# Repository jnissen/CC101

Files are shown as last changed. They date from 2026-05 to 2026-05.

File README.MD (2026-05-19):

*Deutsch | [English](README.en.md)*

# Peerhof-Uni CC1101

KiCad-Projekt für eine kompakte Trägerplatine, die einen **ESP8266 (Wemos D1 Mini)** mit einem **CC1101 Sub-GHz-Funkmodul** (z. B. 433/868 MHz) kombiniert. Die Platine dient als universelles Funk-Gateway bzw. -Sender/Empfänger und lässt sich z. B. zur Anbindung von 433-MHz-Sensoren, Aktoren oder Smarthome-Komponenten an WLAN nutzen.

<p>
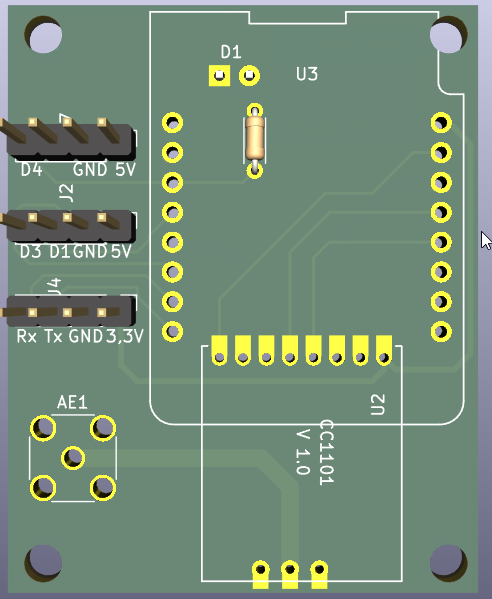
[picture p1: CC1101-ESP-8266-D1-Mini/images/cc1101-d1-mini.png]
CC1101 ESP8266 D1 Mini (Light)
  
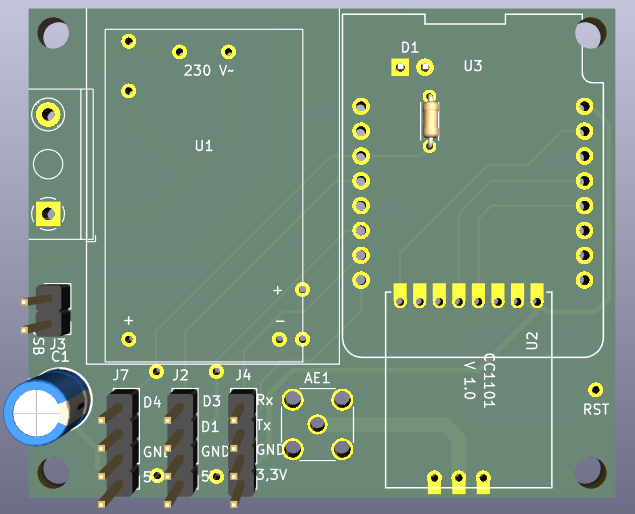
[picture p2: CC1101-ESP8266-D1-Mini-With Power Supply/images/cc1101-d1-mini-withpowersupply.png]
CC1101 ESP8266 D1 Mini mit Netzteil
  
</p>

## Projektvarianten

Das Repository enthält zwei Varianten desselben Designs:

- **[CC1101-ESP-8266-D1-Mini](CC1101-ESP-8266-D1-Mini/)** – *Light-Version*  
  Schlanke Variante ohne eigene Spannungsversorgung. Versorgung erfolgt direkt über den USB-Anschluss bzw. den 5-V-Pin des D1 Mini. Ideal, wenn bereits eine stabile 5-V-Quelle vorhanden ist.

- **[CC1101-ESP8266-D1-Mini-With Power Supply](CC1101-ESP8266-D1-Mini-With%20Power%20Supply/)** – *Variante mit Netzteil*  
  Erweiterte Version mit zusätzlicher Bordspannungsversorgung für den autarken Betrieb (z. B. direkt aus einer höheren DC-Eingangsspannung).

## Funktionen / Merkmale

- ESP8266 auf Basis des Wemos D1 Mini (WLAN, einfache Programmierung über USB).
- CC1101-Funkmodul für Sub-GHz-Kommunikation (ASK/OOK, FSK, GFSK, MSK).
- Herausgeführte Stiftleisten:
  - `J2`: D4 / GND / 5 V
  - `J3`: D3 / D1 / GND / 5 V
  - `J4`: RX / TX / GND / 3,3 V (UART)
- Pad-Feld `AE1` für eine externe Antenne / Helix-Antenne.
- Status-LED `D1`.
- Zweilagiges PCB-Design, fertige Gerber-Daten liegen jeweils im Ordner `gerber/`.

## Verzeichnisstruktur

```
CC1101-ESP-8266-D1-Mini/                  KiCad-Projekt (Light)
CC1101-ESP8266-D1-Mini-With Power Supply/ KiCad-Projekt (mit Netzteil)
└── gerber/                               Fertigungsdaten (Gerber + Bohrdatei)
```

## Verwendung

1. Projekt in **KiCad** öffnen (`.kicad_pro`).
2. Schaltplan (`.kicad_sch`) und Layout (`.kicad_pcb`) prüfen bzw. anpassen.
3. Gerber-Daten aus dem jeweiligen `gerber/`-Ordner an einen PCB-Hersteller übermitteln.
4. Bestücken, ESP8266 mit gewünschter Firmware flashen (z. B. ESPHome, Tasmota mit CC1101-Patch, eigene Arduino-Skizze) und an SPI-Pins des D1 Mini anschließen.

## Bezugsquellen

- CC1101-Funkmodul (Amazon, Affiliate-Link): <https://amzn.to/4uQriL0>
- Wemos D1 Mini (ESP8266) (Amazon, Affiliate-Link): <https://amzn.to/4tIXEXa>

## Lizenz

Dieses Projekt steht unter der **CERN-OHL-W-2.0** Lizenz: <https://ohwr.org/cern_ohl_w_v2.txt>

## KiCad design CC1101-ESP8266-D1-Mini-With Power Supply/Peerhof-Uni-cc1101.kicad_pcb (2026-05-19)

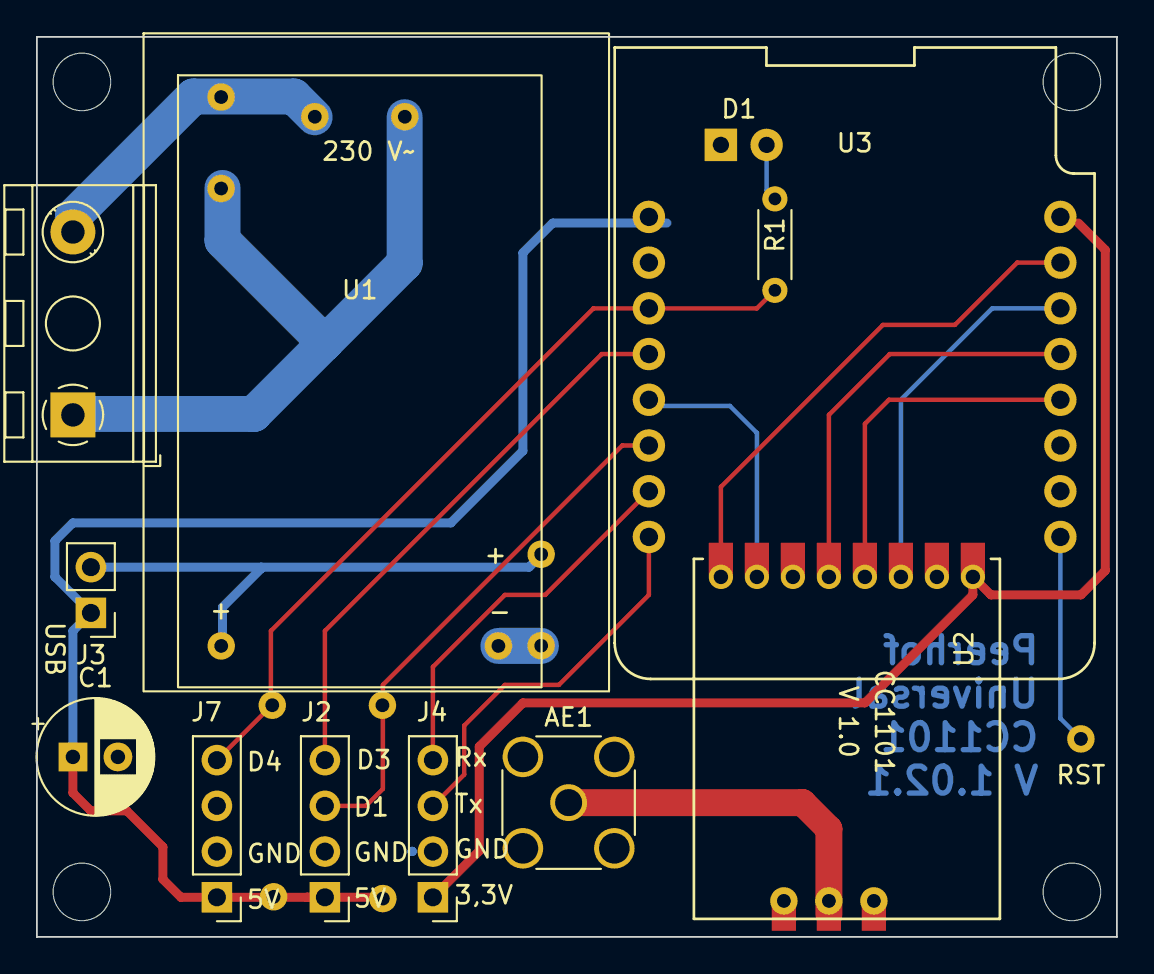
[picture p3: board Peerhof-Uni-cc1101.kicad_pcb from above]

Board: 2 copper layers, 60.0 x 50.0 mm, 12 parts (1 on the bottom side), 18 nets.

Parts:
AE1: Antenna_Shield; SMA_Wurth_60312002114503_Vertical
C1: C_Polarized_Small; CP_Radial_D6.3mm_P2.50mm
D1: LED; LED_D1.8mm_W1.8mm_H2.4mm_Horizontal_O3.81mm_Z1.6mm
J1: Screw_Terminal_01x02; TerminalBlock_RND_205-00241_1x02_P10.16mm_Horizontal
J2: ToF(D1/D2); PinHeader_1x04_P2.54mm_Vertical
J3: Conn_01x02_Male; PinHeader_1x02_P2.54mm_Vertical
J4: Rx/Tx; PinHeader_1x04_P2.54mm_Vertical
J7: DHT11; PinHeader_1x04_P2.54mm_Vertical
R1: 470K; R_Axial_DIN0204_L3.6mm_D1.6mm_P5.08mm_Horizontal
U1: AC-05-3; HLK-PM01-AC-05-3
U2: CC1101
U3: WeMos_D1_mini; wemos-d1-mini-with-pin-header-and-connector

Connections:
+3.3V: J4.1, U2.1 (VCC), U3.8 (3.3V)
+5V: C1.1, J2.1, J3.1, J7.1, U3.9 (5V)
D1: J2.3, U3.14 (D1)
D2: U2.7 (GDO0), U3.13 (D2)
D3: J2.4, U3.12 (D3)
D4: J7.4, R1.2, U3.11 (D4)
D5: U2.4 (SCLK), U3.4 (D5)
D6: U2.5 (MISO), U3.5 (D6)
D7: U2.3 (MOSI), U3.6 (D7)
D8: U2.8 (CSN), U3.7 (D8)
GND: AE1.2 (Shield), C1.2, D1.1 (K), J2.2, J4.2, J7.2, U1.5 (-V), U2.2 (GND), U2.9 (GND), U2.11 (GND), U3.10 (GND)
unnamed: AE1.1 (A), U2.10 (Antenna)
unnamed: D1.2 (A), R1.1
unnamed: J1.1, U1.2 (N)
unnamed: J1.2, U1.1 (L)
unnamed: J3.2, U1.4 (+V)
Rx: J4.4, U3.15 (Rx)
Tx: J4.3, U3.16 (Tx)

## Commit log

2026-05-19 Initial PCB V 1.02.1
    [Peerhof-Uni-CC1101 Light-B_Cu.gbr, Peerhof-Uni-CC1101 Light-B_Mask.gbr, Peerhof-Uni-CC1101 Light-B_Paste.gbr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]
2026-05-19 Kicad Version 10.0
    [Peerhof-Uni-CC1101 Light.kicad_pcb]
2026-05-19 with power Supply Project
    [Peerhof-Uni-cc1101-B_Cu.gbr, Peerhof-Uni-cc1101-B_Mask.gbr, Peerhof-Uni-cc1101-B_Paste.gbr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]
2026-05-19 Switch project license to CERN-OHL-W
    Replaces the public domain Unlicense with the CERN Open Hardware Licence v2 - Weakly Reciprocal. This change promotes collaboration and ensures derivative works of the hardware designs remain open under compatible terms.
2026-05-19 docs: README aktualisiert mit Projektbeschreibung und Funktionen
2026-05-19 chore: Leere Code-Änderungen ohne spezifische Anpassungen hinzugefügt
    [Peerhof-Uni-cc1101-B_Cu.gbr, Peerhof-Uni-cc1101-B_Mask.gbr, Peerhof-Uni-cc1101-B_Paste.gbr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]
2026-05-19 docs: README aktualisiert und englische Übersetzung hinzugefügt
2026-05-19 docs: Bezugsquellen für CC1101 und Wemos D1 Mini im README hinzugefügt
